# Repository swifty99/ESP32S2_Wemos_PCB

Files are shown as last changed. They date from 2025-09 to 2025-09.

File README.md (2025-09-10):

# ESP32S2_Wemos_PCB
Handy adapter to make use of all the IO.
ESP Devices have so many nice interfaces. This PCB adds:
- protection due to dumbness (serial 100Ohms save you electronics big time)
- nice plugs XH plugs work great
- protect against magic smoke from dumb inverse power
- add MosFETs to switch fast and reliable without extra hardwere
- select different power levels for connectors with solder jumpers

This is a Kicad project, feel free to improve. Or just upload the pcb file to the manufacturer you like

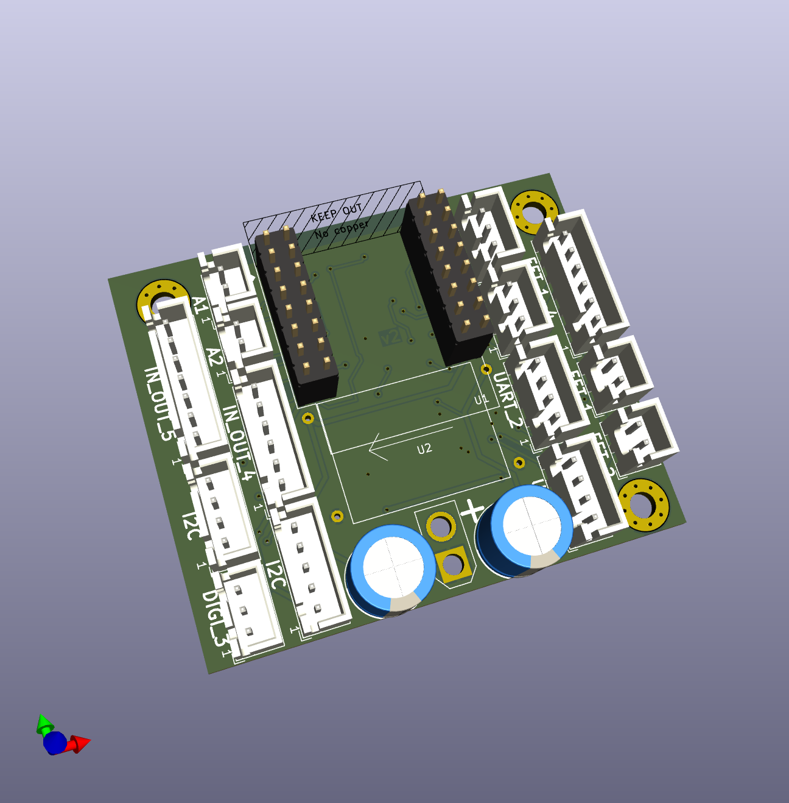
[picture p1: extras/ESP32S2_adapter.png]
front view


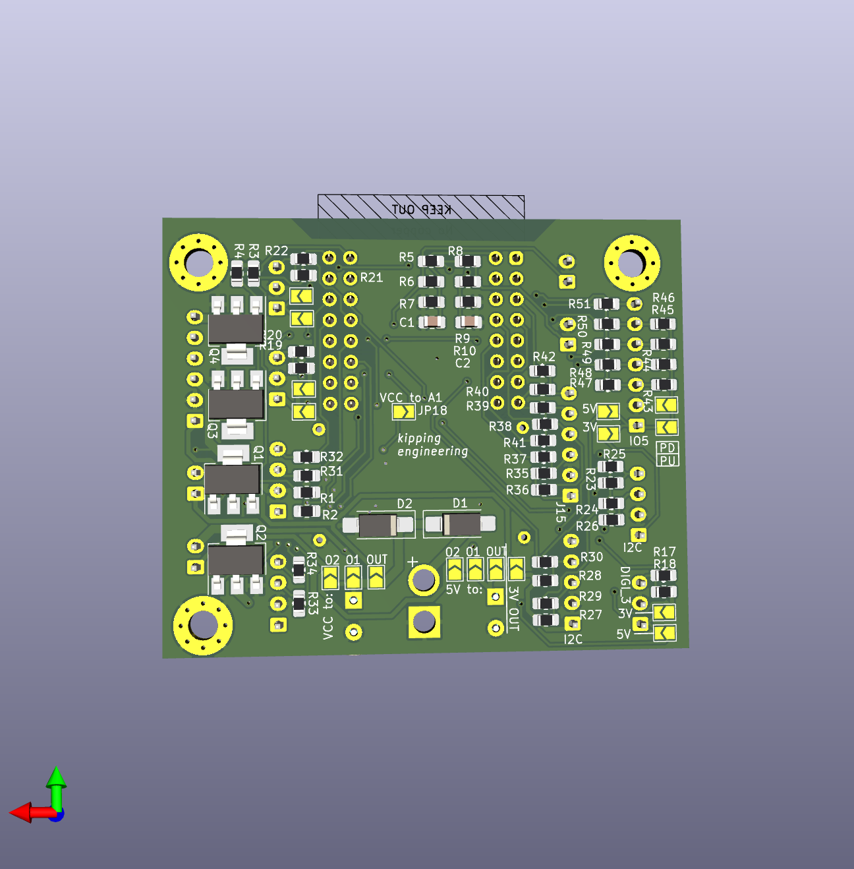
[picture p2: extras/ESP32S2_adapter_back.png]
rear view


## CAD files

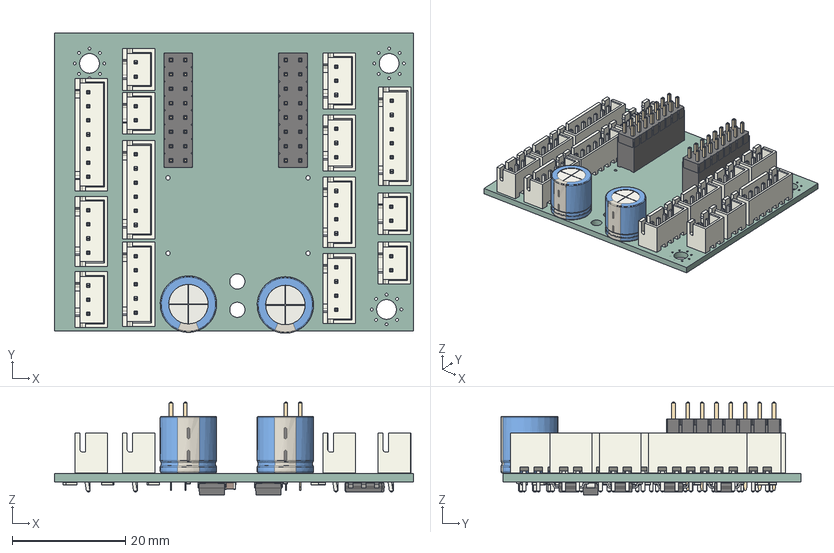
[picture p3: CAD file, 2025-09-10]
ESP32S2_adapter.step
63.5 x 53.2 x 16.4 mm
JST_XH_B2B-XH-A_1x02_P2.50mm_Vertical x 4
JST_XH_B6B-XH-A_1x06_P2.50mm_Vertical x 2
JST_XH_B3B-XH-A_1x03_P2.50mm_Vertical x 3
PinHeader_2x08_P2.54mm_Vertical x 2
PinSocket_2x08_P2.54mm_Vertical x 2
JST_XH_B7B-XH-A_1x07_P2.50mm_Vertical
CP_Radial_D10.0mm_P3.80mm x 2
JST_XH_B4B-XH-A_1x04_P2.50mm_Vertical x 3
JST_XH_B5B-XH-A_1x05_P2.50mm_Vertical
R_0805_2012Metric x 45
SOT-223 x 4
D_SMA x 2
C_0805_2012Metric x 2
ESP32S2_adapter_PCB

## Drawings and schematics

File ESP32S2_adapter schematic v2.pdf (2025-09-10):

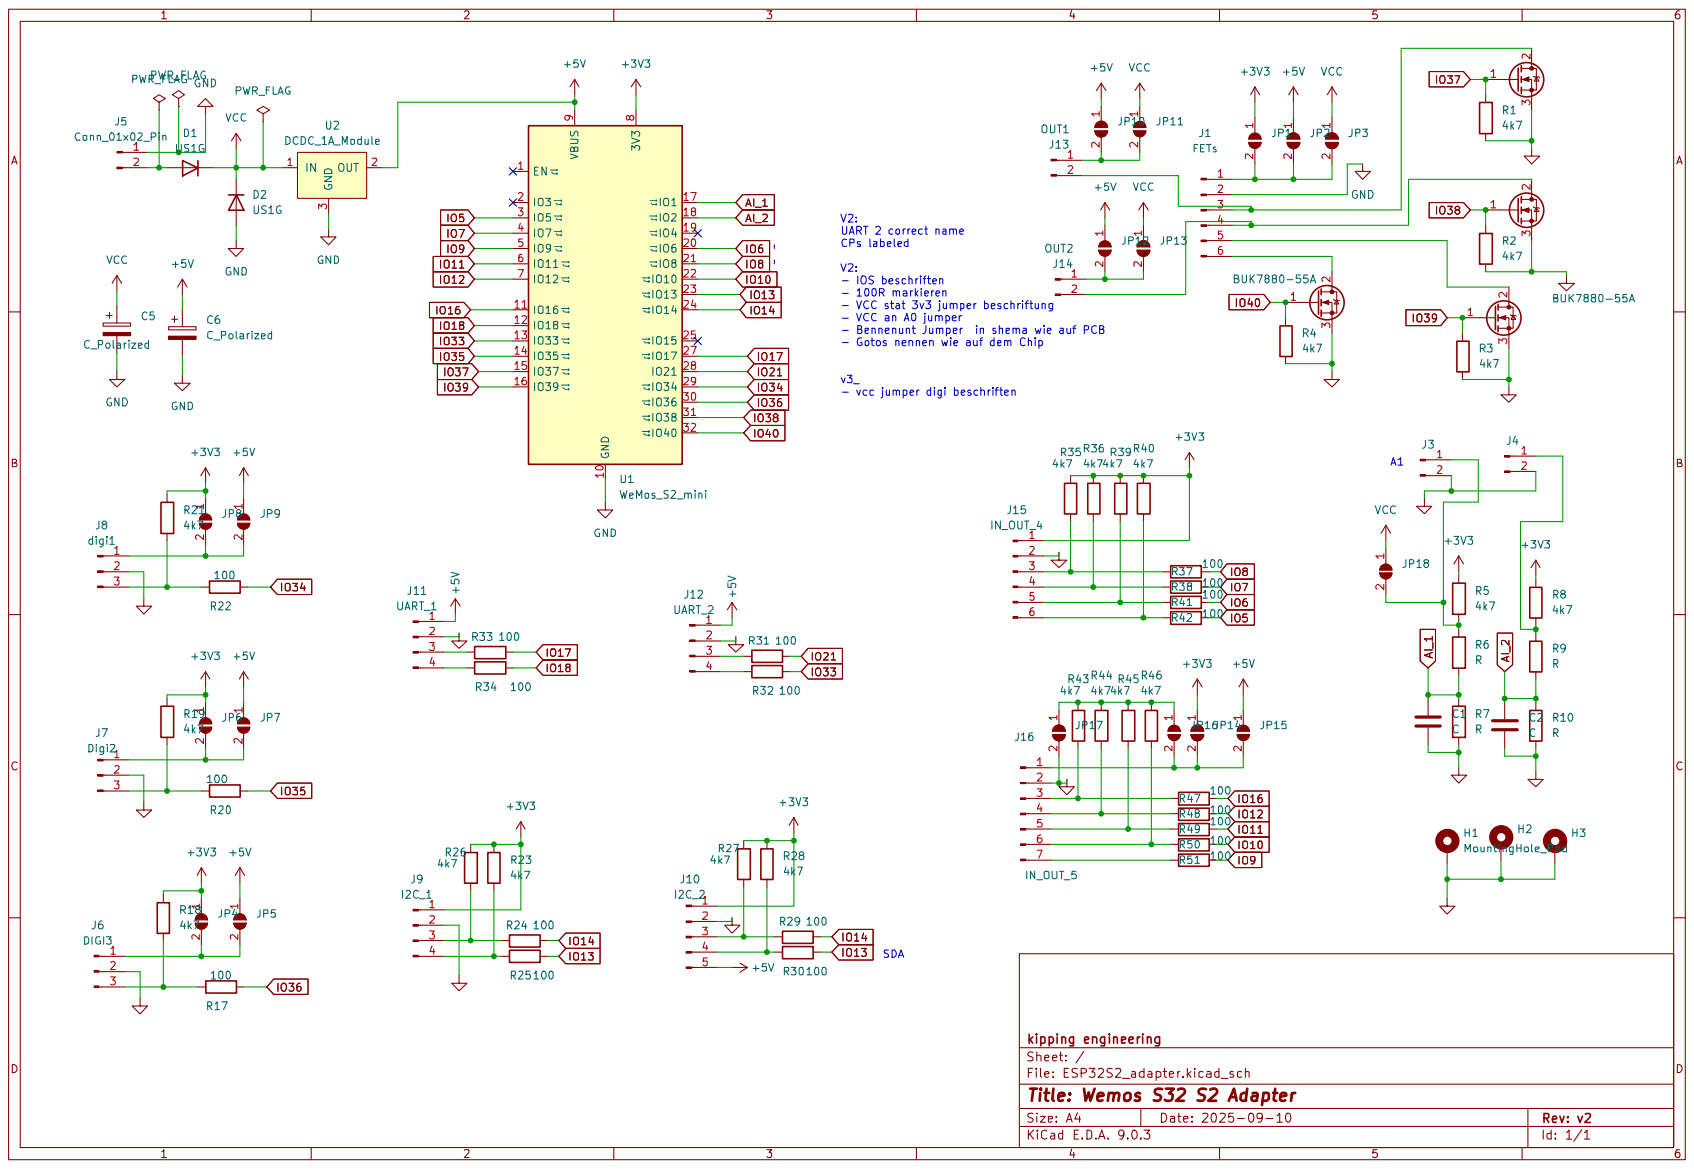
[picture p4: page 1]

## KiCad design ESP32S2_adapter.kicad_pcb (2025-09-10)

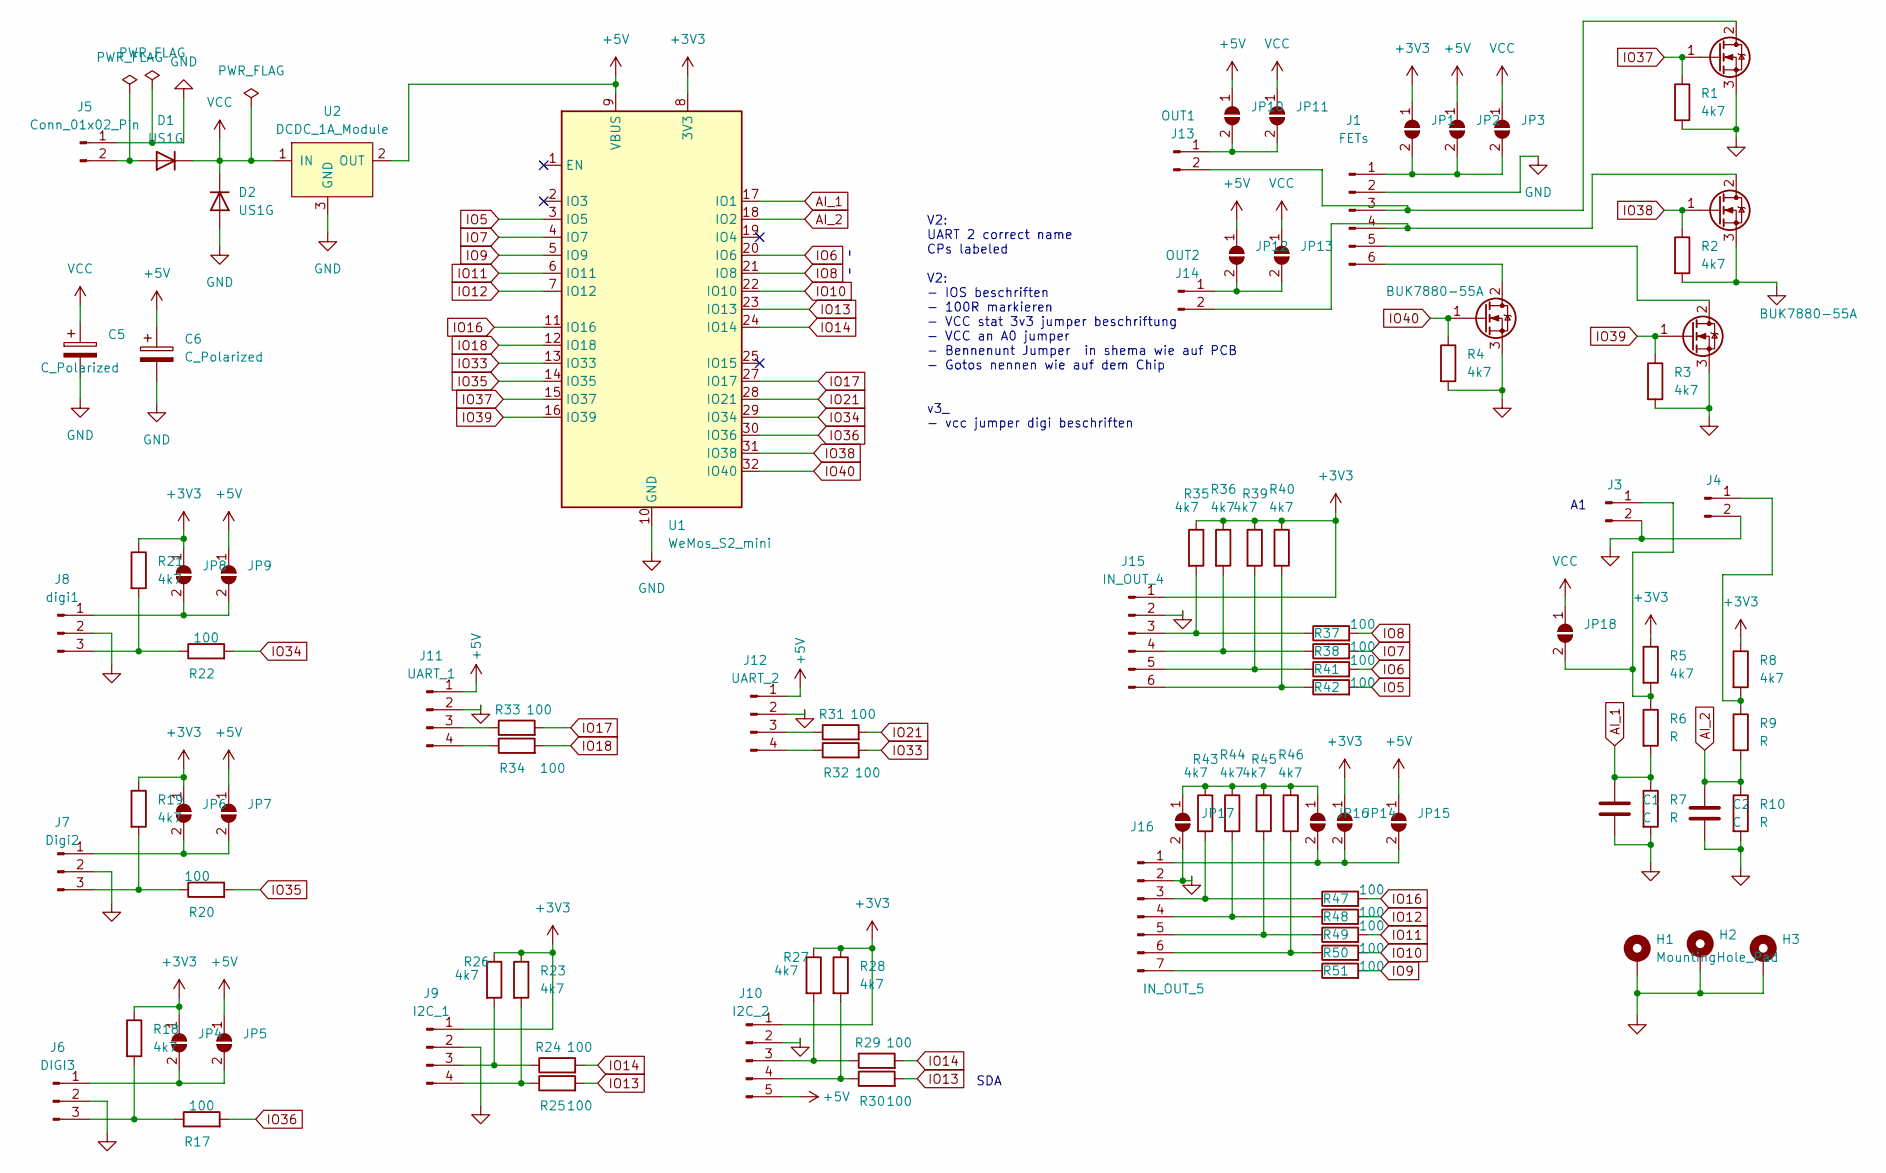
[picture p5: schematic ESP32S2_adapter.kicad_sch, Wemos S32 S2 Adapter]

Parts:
C1, C2: C; C_0805_2012Metric_Pad1.18x1.45mm_HandSolder
C5, C6: C_Polarized; CP_Radial_D10.0mm_P3.80mm
D1, D2: US1G; D_SMA_Handsoldering
H1, H2, H3: MountingHole_Pad; MountingHole_3.5mm_Pad_Via
J1: FETs; JST_XH_B6B-XH-A_1x06_P2.50mm_Vertical
J3: A0; JST_XH_B2B-XH-A_1x02_P2.50mm_Vertical
J4: A1; JST_XH_B2B-XH-A_1x02_P2.50mm_Vertical
J5: Conn_01x02_Pin; AMASS_XT30U-M_1x02_P5.0mm_Vertical
J6: DIGI3; JST_XH_B3B-XH-A_1x03_P2.50mm_Vertical
J7: Digi2; JST_XH_B3B-XH-A_1x03_P2.50mm_Vertical
J8: digi1; JST_XH_B3B-XH-A_1x03_P2.50mm_Vertical
J9: I2C_1; JST_XH_B4B-XH-A_1x04_P2.50mm_Vertical
J10: I2C_2; JST_XH_B5B-XH-A_1x05_P2.50mm_Vertical
J11: UART_1; JST_XH_B4B-XH-A_1x04_P2.50mm_Vertical
J12: UART_2; JST_XH_B4B-XH-A_1x04_P2.50mm_Vertical
J13: OUT1; JST_XH_B2B-XH-A_1x02_P2.50mm_Vertical
J14: OUT2; JST_XH_B2B-XH-A_1x02_P2.50mm_Vertical
J15: IN_OUT_4; JST_XH_B6B-XH-A_1x06_P2.50mm_Vertical
J16: IN_OUT_5; JST_XH_B7B-XH-A_1x07_P2.50mm_Vertical
JP1, JP4, JP6, JP8, JP14: 3V3; SolderJumper-2_P1.3mm_Open_TrianglePad1.0x1.5mm
JP2, JP5, JP7, JP9, JP10, JP12, JP15: 5V; SolderJumper-2_P1.3mm_Open_TrianglePad1.0x1.5mm
JP3, JP13, JP18: VCC; SolderJumper-2_P1.3mm_Open_TrianglePad1.0x1.5mm
JP11, JP16: SolderJumper_2_Open; SolderJumper-2_P1.3mm_Open_TrianglePad1.0x1.5mm
JP17: GND; SolderJumper-2_P1.3mm_Open_TrianglePad1.0x1.5mm
Q1, Q2, Q3, Q4: BUK7880-55A; SOT-223-3_TabPin2
R1, R2, R3, R4, R5, R8, R18, R19, R21, R23, R26, R27, R28, R35, R36, R39, R40, R43, R44, R45, R46: 4k7; R_0805_2012Metric_Pad1.20x1.40mm_HandSolder
R6, R7, R9, R10: R; R_0805_2012Metric_Pad1.20x1.40mm_HandSolder
R17, R20, R22, R24, R25, R29, R30, R31, R32, R33, R34, R37, R38, R41, R42, R47, R48, R49, R50, R51: 100; R_0805_2012Metric_Pad1.20x1.40mm_HandSolder
U1: WeMos_S2_mini; WEMOS_S2_mini
U2: DCDC_1A_Module; DCDC_1A_module_bonded

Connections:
+3V3: J9.1, J10.1, J15.1, JP1.1 (A), JP4.1 (A), JP6.1 (A), JP8.1 (A), JP14.1 (A), R5.1, R8.1, R18.1, R19.1, R21.1, R23.1, R26.1, R27.1, R28.1, R35.1, R36.1, R39.1, R40.1, U1.8 (3V3)
+5V: C6.1, J10.5, J11.1, J12.1, JP2.1 (A), JP5.1 (A), JP7.1 (A), JP9.1 (A), JP10.1 (A), JP12.1 (A), JP15.1 (A), U1.9 (VBUS), U2.2 (OUT)
AI_1: C1.1, R6.2, R7.1, U1.17 (IO1)
AI_2: C2.1, R9.2, R10.1, U1.18 (IO2)
GND: C1.2, C2.2, C5.2, C6.2, D2.2 (A), H1.1, H2.1, H3.1, J1.2, J3.2, J4.2, J5.1, J6.2, J7.2, J8.2, J9.2, J10.2, J11.2, J12.2, J15.2, J16.2, JP17.2 (B), Q1.3 (S), Q2.3 (S), Q3.3 (S), Q4.3 (S), R1.2, R2.2, R3.2, R4.2, R7.2, R10.2, U1.10 (GND), U1.26 (GND), U2.3 (GND)
IO5: R42.2, U1.3 (IO5)
IO6: R41.2, U1.20 (IO6)
IO7: R38.2, U1.4 (IO7)
IO8: R37.2, U1.21 (IO8)
IO9: R51.2, U1.5 (IO9)
IO10: R50.2, U1.22 (IO10)
IO11: R49.2, U1.6 (IO11)
IO12: R48.2, U1.7 (IO12)
IO13: R25.2, R30.2, U1.23 (IO13)
IO14: R24.2, R29.2, U1.24 (IO14)
IO16: R47.2, U1.11 (IO16)
IO17: R33.2, U1.27 (IO17)
IO18: R34.2, U1.12 (IO18)
IO21: R31.2, U1.28 (IO21)
IO33: R32.2, U1.13 (IO33)
IO34: R22.2, U1.29 (IO34)
IO35: R20.2, U1.14 (IO35)
IO36: R17.2, U1.30 (IO36)
IO37: Q1.1 (G), R1.1, U1.15 (IO37)
IO38: Q2.1 (G), R2.1, U1.31 (IO38)
IO39: Q3.1 (G), R3.1, U1.16 (IO39)
IO40: Q4.1 (G), R4.1, U1.32 (IO40)
unnamed: D1.2 (A), J5.2
unnamed: J1.1, JP1.2 (B), JP2.2 (B), JP3.2 (B)
unnamed: J1.3, J13.2, Q1.2 (D)
unnamed: J1.4, J14.2, Q2.2 (D)
unnamed: J1.5, Q3.2 (D)
unnamed: J1.6, Q4.2 (D)
unnamed: J3.1, JP18.2 (B), R5.2, R6.1
unnamed: J4.1, R8.2, R9.1
unnamed: J6.1, JP4.2 (B), JP5.2 (B)
unnamed: J6.3, R17.1, R18.2
unnamed: J7.1, JP6.2 (B), JP7.2 (B)
unnamed: J7.3, R19.2, R20.1
unnamed: J8.1, JP8.2 (B), JP9.2 (B)
unnamed: J8.3, R21.2, R22.1
unnamed: J9.3, R24.1, R26.2
unnamed: J9.4, R23.2, R25.1
unnamed: J10.3, R27.2, R29.1
unnamed: J10.4, R28.2, R30.1
unnamed: J11.3, R33.1
unnamed: J11.4, R34.1
unnamed: J12.3, R31.1
unnamed: J12.4, R32.1
unnamed: J13.1, JP10.2 (B), JP11.2 (B)
unnamed: J14.1, JP12.2 (B), JP13.2 (B)
unnamed: J15.3, R35.2, R37.1
unnamed: J15.4, R36.2, R38.1
unnamed: J15.5, R39.2, R41.1
unnamed: J15.6, R40.2, R42.1
unnamed: J16.1, JP14.2 (B), JP15.2 (B), JP16.2 (B)
unnamed: J16.3, R43.2, R47.1
unnamed: J16.4, R44.2, R48.1
unnamed: J16.5, R45.2, R49.1
unnamed: J16.6, R46.2, R50.1
unnamed: J16.7, R51.1
unnamed: JP16.1 (A), JP17.1 (A), R43.1, R44.1, R45.1, R46.1
VCC: C5.1, D1.1 (K), D2.1 (K), JP3.1 (A), JP11.1 (A), JP13.1 (A), JP18.1 (A), U2.1 (IN)

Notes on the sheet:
V2: UART 2 correct name CPs labeled V2: - IOS beschriften - 100R markieren - VCC stat 3v3 jumper beschriftung - VCC an A0 jumper - Bennenunt Jumper in shema wie auf PCB - Gotos nennen wie auf dem Chip v3_ - vcc jumper digi beschriften
SDA

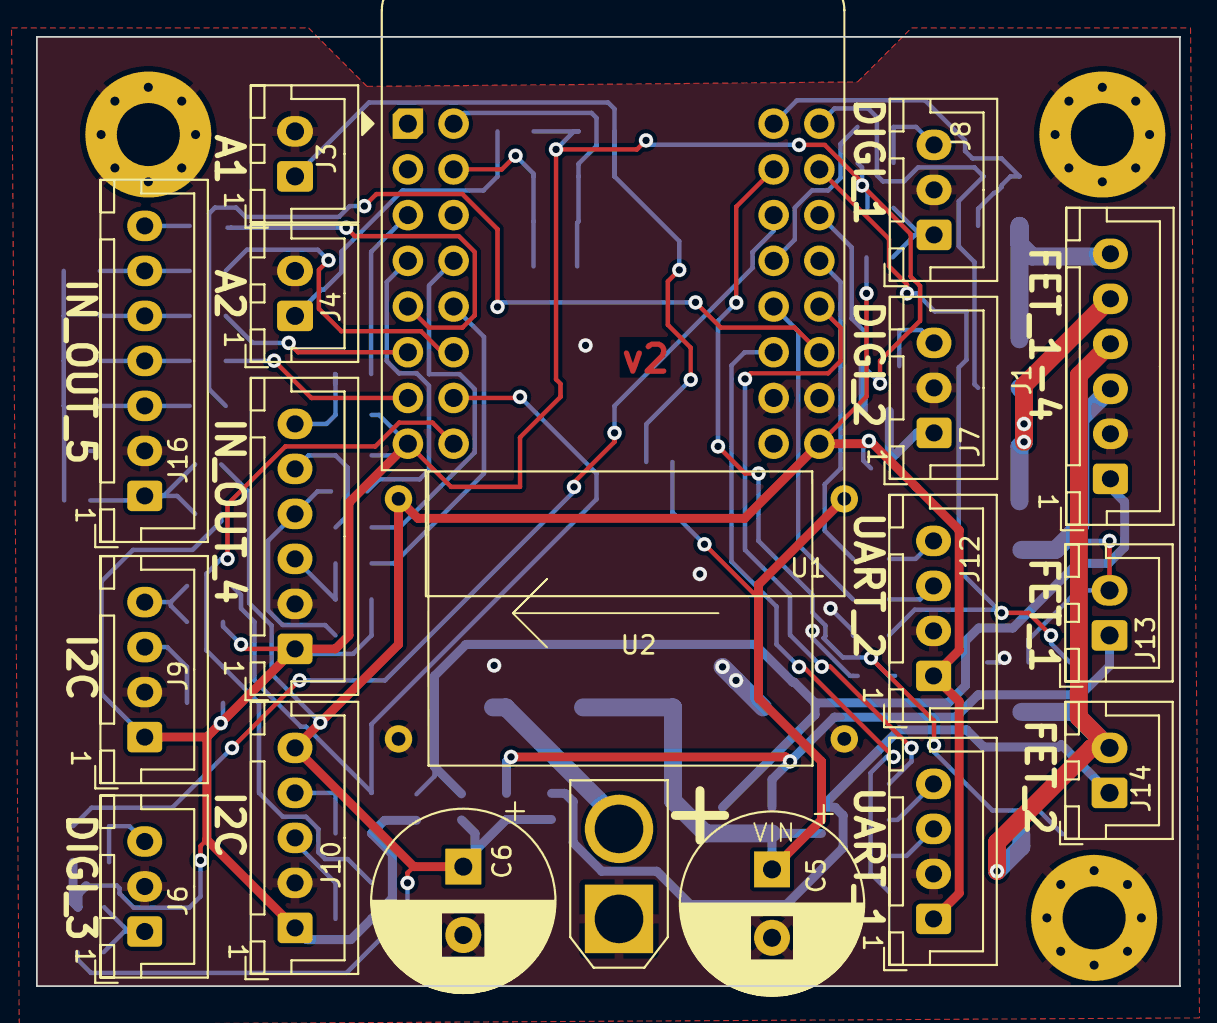
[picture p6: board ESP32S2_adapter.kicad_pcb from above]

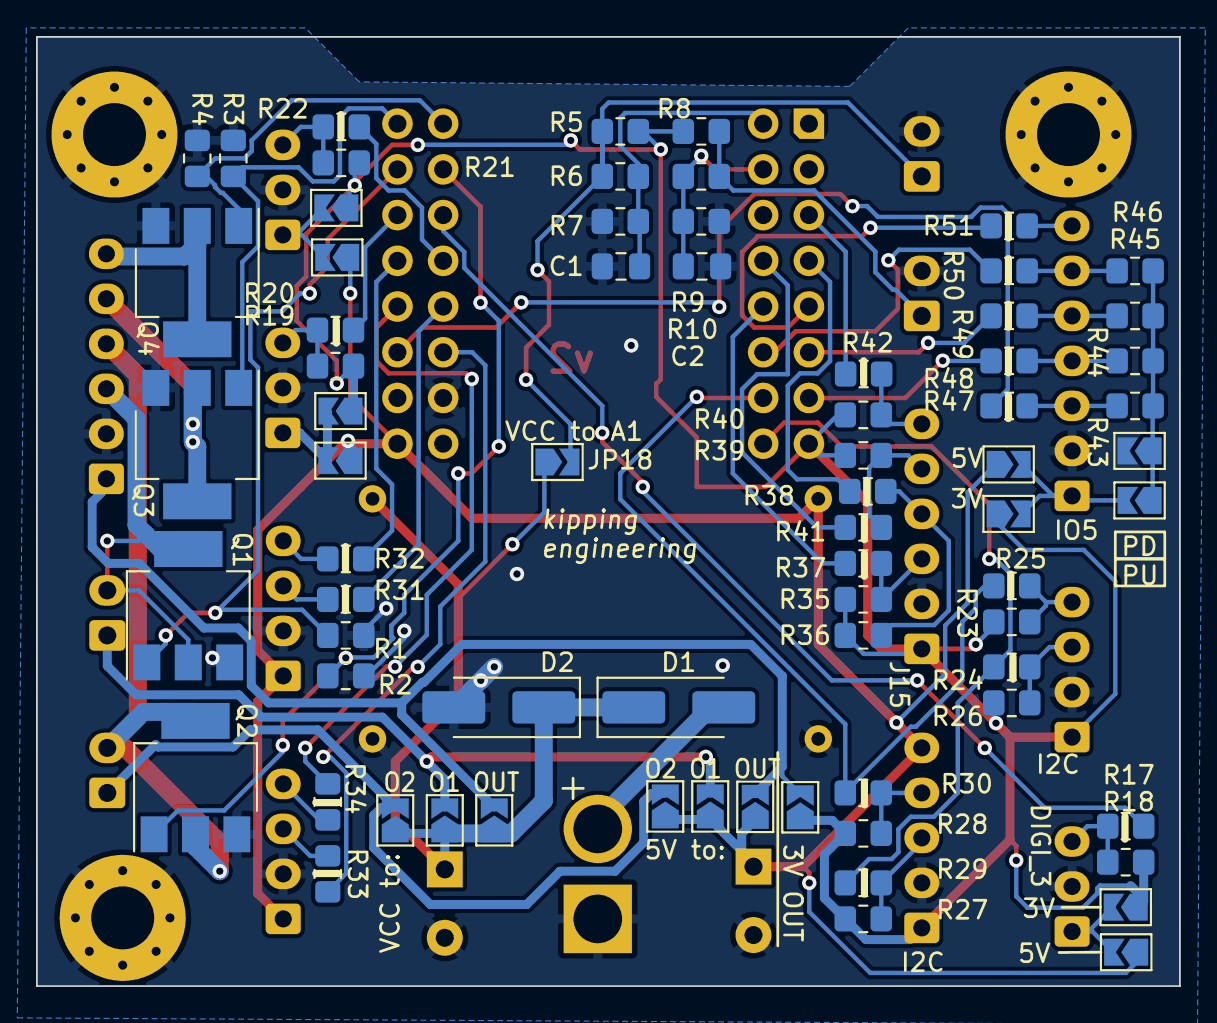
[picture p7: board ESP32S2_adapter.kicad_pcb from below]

Board: 2 copper layers, 63.5 x 52.7 mm, 93 parts (71 on the bottom side), 63 nets.

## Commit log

2025-09-10 Add KiCad backup and cache files to .gitignore
2025-09-10 comment update
    [ESP32S2_adapter.kicad_sch]
2025-09-10 3d added
    [ESP32S2_adapter.step]
2025-09-10 Add note on selecting power levels for connectors
